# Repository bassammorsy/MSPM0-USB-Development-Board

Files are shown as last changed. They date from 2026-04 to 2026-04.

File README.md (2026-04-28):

# MSPM0 USB Development Board

A 2-layer development board built around the Texas Instruments MSPM0
microcontroller, designed for prototyping and peripheral interfacing
via USB-C.

## Features
- TI MSPM0 microcontroller
- USB-C connector with CH340 USB-to-UART bridge for serial communication
- Manually routed USB differential pair with impedance matching
- Crystal oscillator with datasheet-compliant layout guidelines
- I2C header for connecting external sensors and peripherals
- Hardware reset circuit via NRST line
- Decoupling capacitors on all IC power pins
- 3.3V power regulation from 5V VBUS
- Dual-layer GND copper pour
- Mounting holes at all four corners

## Specs
- Layers: 2
- Pads: 205
- Nets: 61
- Track Segments: 328

## Tools
- KiCad 9

## Files
- `/gerbers` — fabrication-ready Gerber and drill files
- `MSPM0.kicad_pcb` — PCB layout
- `MSPM0.kicad_sch` — schematic
- `MSPM0.kicad_pro` — project file

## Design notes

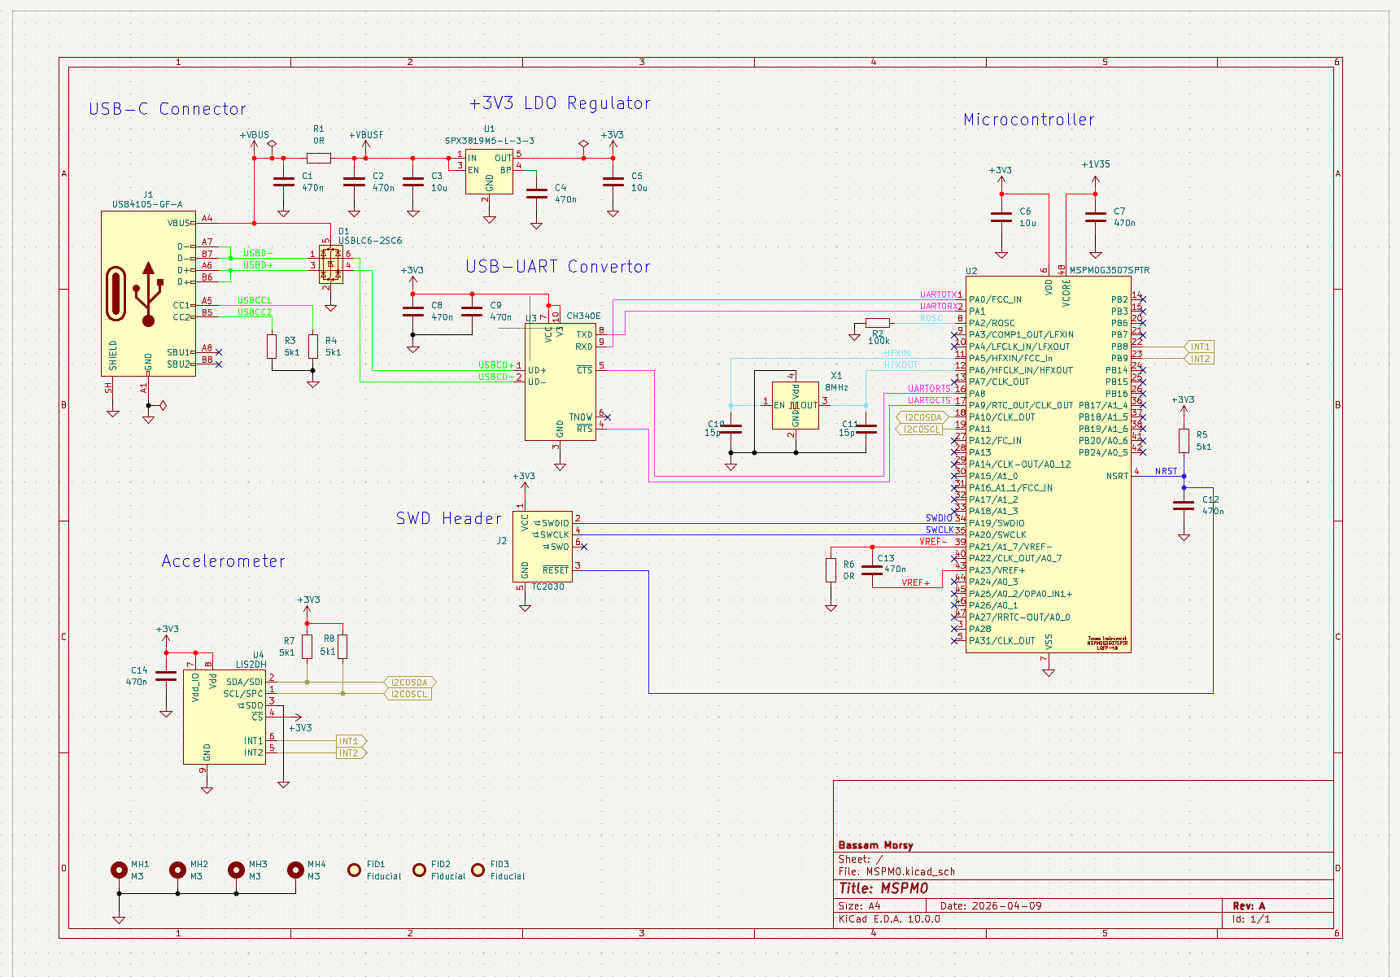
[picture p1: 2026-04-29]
MSPM0_Schematic_screenshot.png

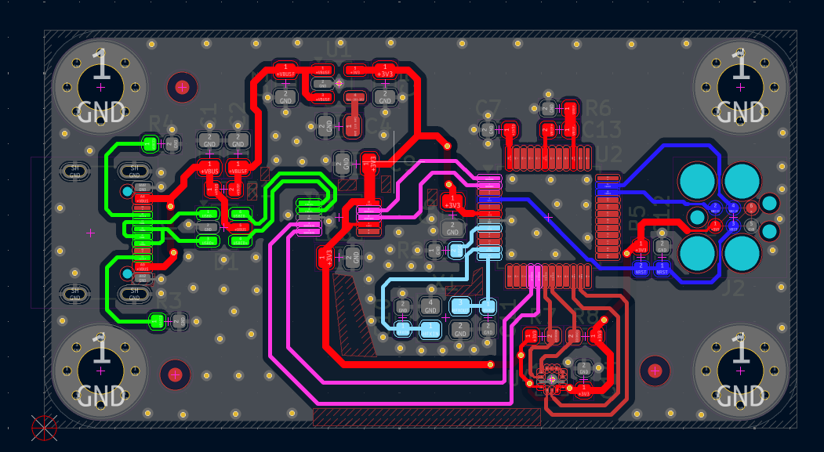
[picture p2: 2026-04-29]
MSPM0_pcb_screenshot.png

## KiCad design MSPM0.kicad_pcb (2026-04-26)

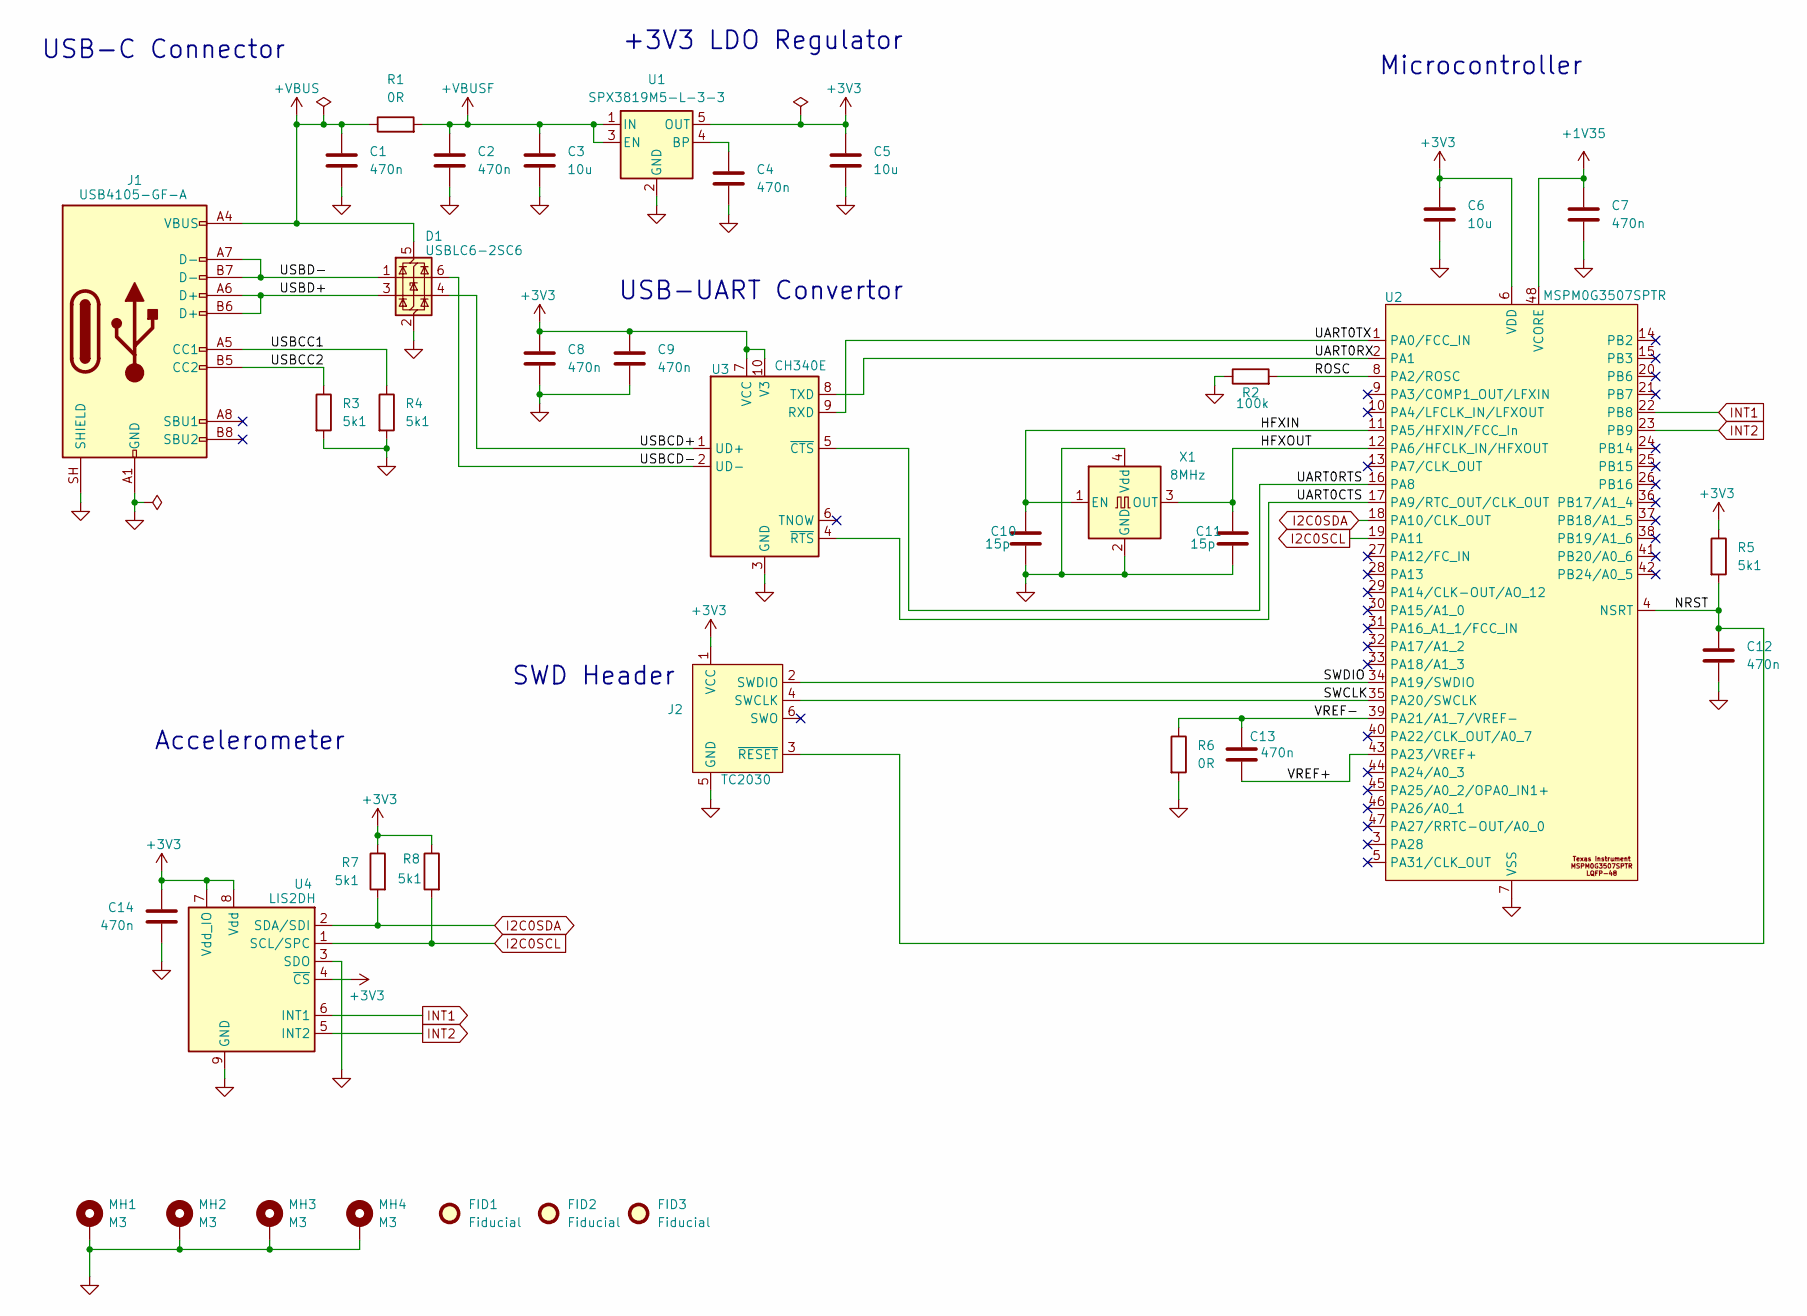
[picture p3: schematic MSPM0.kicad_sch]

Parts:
C1, C2, C4, C8, C9: 470n; C_0805_2012Metric
C3, C5, C6: 10u; C_0805_2012Metric
C7, C12, C13, C14: 470n; C_0603_1608Metric
C10, C11: 15p; C_0603_1608Metric
D1: USBLC6-2SC6; SOT-23-6
FID1, FID2, FID3: Fiducial; Fiducial_1mm_Mask2mm
J1: USB4105-GF-A; USB_C_Receptacle_GCT_USB4105-xx-A_16P_TopMnt_Horizontal
J2: TC2030; Tag-Connect_TC2030-IDC-FP_2x03_P1.27mm_Vertical
MH1, MH2, MH3, MH4: M3; MountingHole_3.2mm_M3_Pad_Via
R1, R6: 0R; C_0603_1608Metric
R2: 100k; C_0603_1608Metric
R3, R4, R5, R7, R8: 5k1; C_0603_1608Metric
U1: SPX3819M5-L-3-3; SOT-23-5
U2: MSPM0G3507SPTR; LQFP-48_7x7mm_P0.5mm; Part Number MSPM0G3507SPTR
U3: CH340E; MSOP-10_3x3mm_P0.5mm
U4: LIS2DH; LGA-14_2x2mm_P0.35mm_LayoutBorder3x4y
X1: 8MHz; Oscillator_SMD_Abracon_ASE-4Pin_3.2x2.5mm

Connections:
+1V35: C7.1, U2.48 (VCORE)
+3V3: C5.1, C6.1, C8.1, C9.1, C14.1, J2.1 (VCC), R5.1, R7.1, R8.1, U1.5 (OUT), U2.6 (VDD), U3.7 (VCC), U3.10 (V3), U4.4 (~CS), U4.7 (Vdd_IO), U4.8 (Vdd)
+VBUS: C1.1, D1.5 (VBUS), J1.A4 (VBUS), J1.A9 (VBUS), J1.B4 (VBUS), J1.B9 (VBUS), R1.1
+VBUSF: C2.1, C3.1, R1.2, U1.1 (IN), U1.3 (EN)
/HFXIN: C10.1, U2.11 (PA5/HFXIN/FCC_In), X1.1 (EN)
/HFXOUT: C11.1, U2.12 (PA6/HFCLK_IN/HFXOUT), X1.3 (OUT)
/NRST: C12.1, J2.3 (~RESET), R5.2, U2.4 (NSRT)
/ROSC: R2.2, U2.8 (PA2/ROSC)
/SWCLK: J2.4 (SWCLK), U2.35 (PA20/SWCLK)
/SWDIO: J2.2 (SWDIO), U2.34 (PA19/SWDIO)
/UART0CTS: U2.17 (PA9/RTC_OUT/CLK_OUT), U3.4 (~RTS)
/UART0RTS: U2.16 (PA8), U3.5 (~CTS)
/UART0RX: U2.2 (PA1), U3.8 (TXD)
/UART0TX: U2.1 (PA0/FCC_IN), U3.9 (RXD)
/USBCC1: J1.A5 (CC1), R4.1
/USBCC2: J1.B5 (CC2), R3.1
/USBCD+: D1.4 (I/O2), U3.1 (UD+)
/USBCD-: D1.6 (I/O1), U3.2 (UD-)
/USBD+: D1.3 (I/O2), J1.A6 (D+), J1.B6 (D+)
/USBD-: D1.1 (I/O1), J1.A7 (D-), J1.B7 (D-)
/VREF+: C13.2, U2.43 (PA23/VREF+)
/VREF-: C13.1, R6.1, U2.39 (PA21/A1_7/VREF-)
GND: C1.2, C2.2, C3.2, C4.2, C5.2, C6.2, C7.2, C8.2, C9.2, C10.2, C11.2, C12.2, C14.2, D1.2 (GND), J1.A1 (GND), J1.A12 (GND), J1.B1 (GND), J1.B12 (GND), J1.SH (SHIELD), J2.5 (GND), MH1.1 (1_1), MH2.1 (1_1), MH3.1 (1_1), MH4.1 (1_1), R2.1, R3.2, R4.2, R6.2, U1.2 (GND), U2.7 (VSS), U3.3 (GND), U4.3 (SDO), U4.9 (GND), X1.2 (GND), X1.4 (Vdd)
I2C0SCL: R8.2, U2.19 (PA11), U4.1 (SCL/SPC)
I2C0SDA: R7.2, U2.18 (PA10/CLK_OUT), U4.2 (SDA/SDI)
INT1: U2.22 (PB8), U4.6 (INT1)
INT2: U2.23 (PB9), U4.5 (INT2)
unnamed: C4.1, U1.4 (BP)
unnamed: U4.10 (GND), U4.11 (GND), U4.12 (GND), U4.13 (GND), U4.14 (GND)

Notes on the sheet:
USB-UART Convertor
Accelerometer
USB-C Connector
Microcontroller
SWD Header
+3V3 LDO Regulator

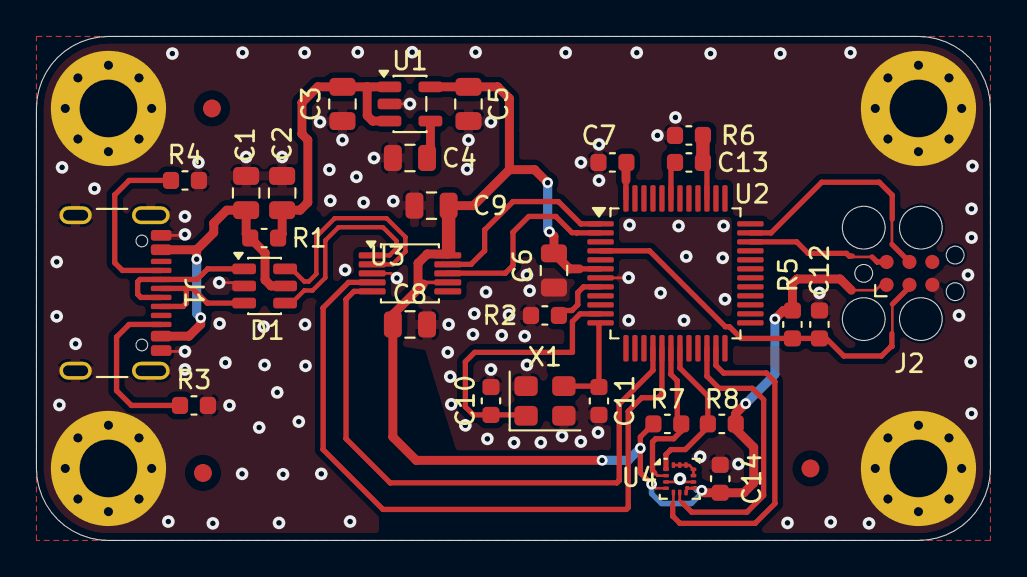
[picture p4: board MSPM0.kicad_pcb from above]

Board: 2 copper layers, 53.0 x 28.0 mm, 37 parts (0 on the bottom side), 29 nets.

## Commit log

2026-04-26 KiCad project files and Gerbers
    [MSPM0-B_Cu.gbr, MSPM0-B_Mask.gbr, MSPM0-B_Paste.gbr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]
2026-04-26 Updated README
    Added detailed description, features, specs, tools, and files for the MSPM0 USB Development Board.
